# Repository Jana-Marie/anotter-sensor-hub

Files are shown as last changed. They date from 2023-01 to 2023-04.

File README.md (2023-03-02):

# anotter-sensor-hub

This is an ESP32-based environmental sensor hub that comes with a Prometheus interface. It is designed to work perfectly with Sensirion SEN05x sensors, such as the depictured SEN055. These sensors provide PM1, PM2.5, PM4, PM10, temperature, humidity, VOC, and NOC indices. In addition, other I2C, SPI, or PWM sensors can be added to the designated connectors. All ESP32 pins are broken out, allowing you to connect any sensor imaginable to the host board.

The PCB and components (w/o SEN055) are about ~5$, with SEN055 it comes up to ~40€/sensor node. 

<table>
  <tbody>
    <tr>
      <td>
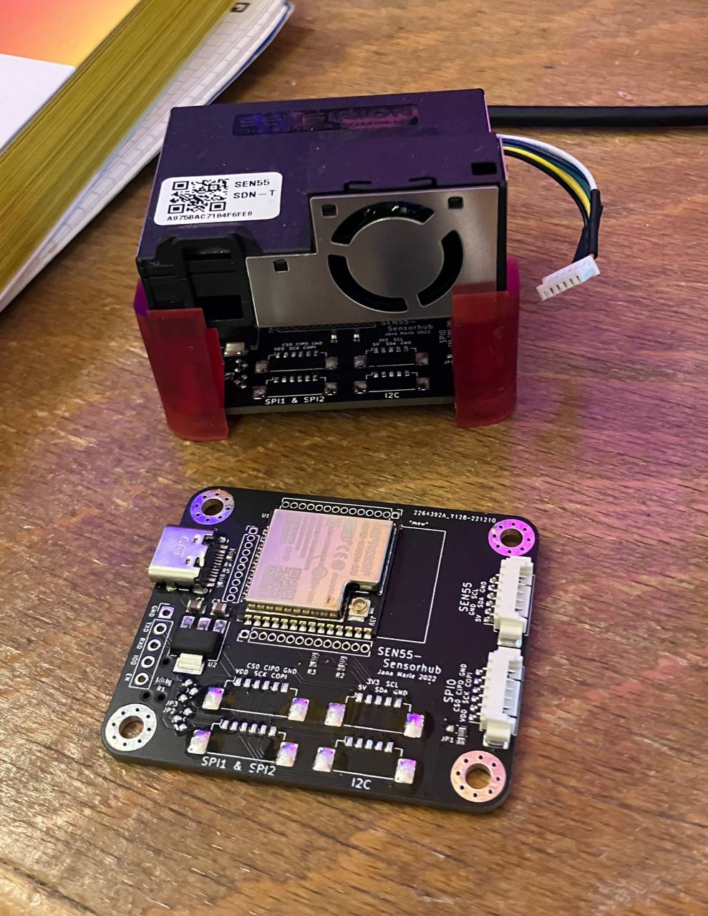
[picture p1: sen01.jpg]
        
      </td>
      <td>
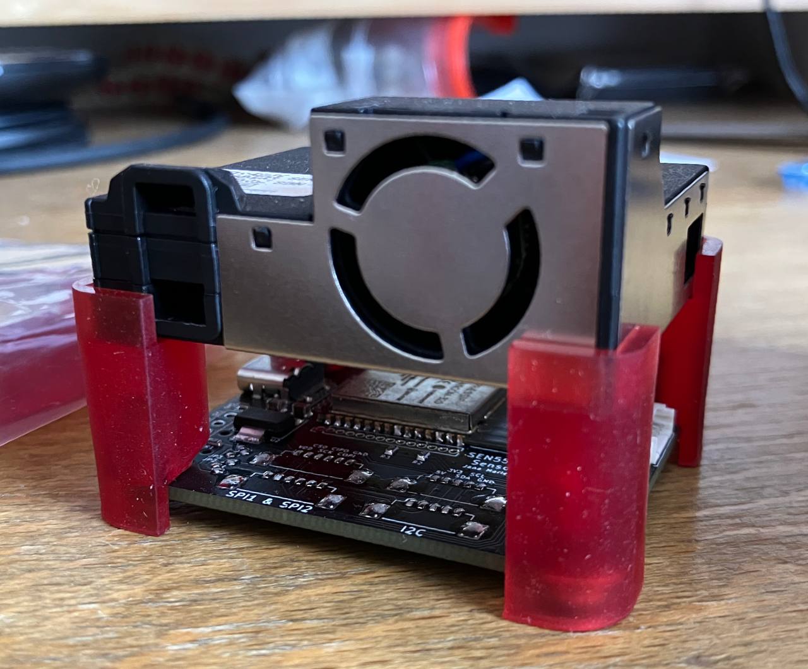
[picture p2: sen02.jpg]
        
      </td>
    </tr>
    <tr>
      <td colspan="2">
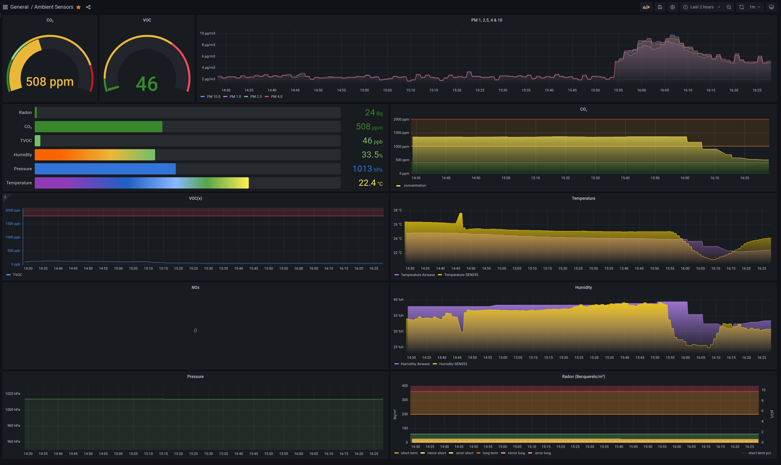
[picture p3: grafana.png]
        
      </td>
    </tr>
  </tbody>
</table>

## Notes

 - Cable: [JST GHR 6Pin to Molex PicoBlade 6Pin](https://www.ebay.de/itm/183753208063)
 - Sensor: [SEN055](https://www.mouser.de/ProductDetail/Sensirion/SEN55-SDN-T)
 - 3D-Print: [4x foot](https://github.com/Jana-Marie/anotter-sensor-hub/blob/main/mechanical/anotter-sensor-hub-foot.stl)

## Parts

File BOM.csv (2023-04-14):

Part | Footprint | Designator | Quantity
1uF | 0805 | C1,C2,C3 | 3
PicoBlade 6P | PicoBlade 6P | J2 | 1
USB Type-C 16P | USB Type-C 16P | J5 | 1
5k1 | 0603 | R1,R2,R3,R4,R5 | 5
ESP32-WROOM-32 | ESP32-WROOM-32 | U1 | 1
AMS1117-3.3 | SOT-223-3 | U2 | 1

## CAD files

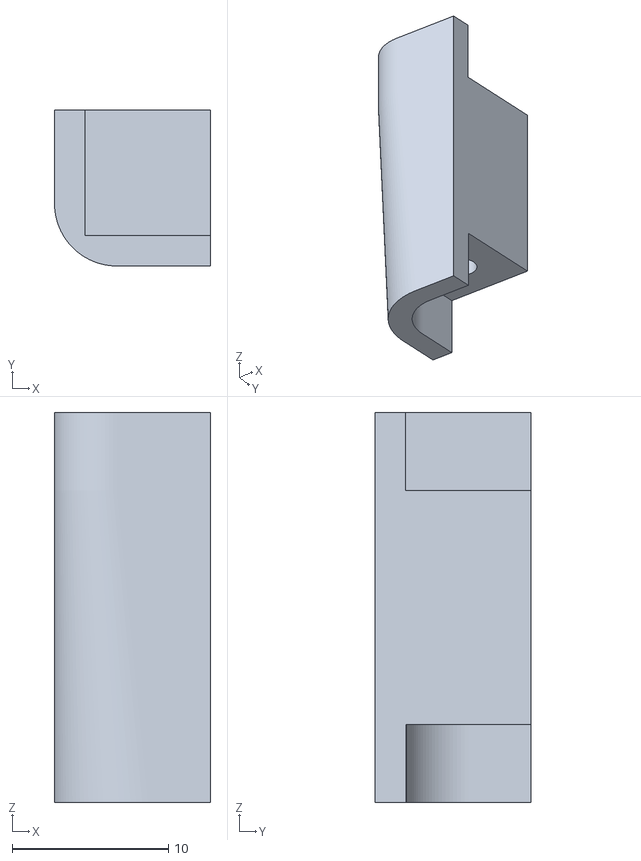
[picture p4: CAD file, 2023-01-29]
mechanical/anotter-sensor-hub-foot.stl
10.0 x 10.0 x 25.0

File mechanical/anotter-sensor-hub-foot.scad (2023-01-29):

$fn = 100;

if($preview){
    pcb();
    translate([1*44.3/2,1*35.3/2,1.6])rotate([0,0,180])stand();
    translate([1*44.3/2,-1*35.3/2,1.6])rotate([0,0,90])stand();
    translate([-1*44.3/2,1*35.3/2,1.6])rotate([0,0,270])stand();
    translate([-1*44.3/2,-1*35.3/2,1.6])rotate([0,0,0])stand();
    translate([0,0,1.6+15])sensor();
} else {
    stand();
}

module stand(h=15,h2=5){
    color("pink")
    difference(){
        union(){
            // outer hull
            hull(){
                // inner structure
                union(){
                    translate([0,2,h/2])cube([8,4,h],center=true);
                    translate([2,0,h/2])cube([4,8,h],center=true);
                    cylinder(r=4,h=h);
                }
                // lower hull
                union(){
                    translate([0,2,-h2/2])cube([12,4,h2],center=true);
                    translate([2,0,-h2/2])cube([4,12,h2],center=true);
                    translate([0,0,-h2])cylinder(r=6,h=h2);
                }
                // upper hull
                union(){
                    translate([0,1,h+h2/2])cube([12,6,h2],center=true);
                    translate([1,0,h+h2/2])cube([6,12,h2],center=true);
                    translate([-2,-2,h])cylinder(r=4,h=h2);
                }
            }
        } union(){
            // screwholes
            translate([0,0,-0.01])cylinder(d=2.8,h=h/3*2);
            // upper cutout
            translate([0,0,h+h/4])cube([8.1,8.1,h/2],center=true);
            // PCB cutout
            union(){
                translate([0,2,-h/2])cube([8,4,h],center=true);
                translate([2,0,-h/2])cube([4,8,h],center=true);
                translate([0,6,0])cube([12,4,h*3],center=true);
                translate([6,0,0])cube([4,12,h*3],center=true);
                translate([0,0,-h])cylinder(r=4,h=h);
            }
        }
    }
}

module pcb(thickness=1.6){
    difference(){
        union(){
            // PCB
            color("green")
            minkowski(){
                r=4;
                translate([0,0,thickness/2-0.1/2])cube([52.3-r-r,43.4-r-r, thickness-0.1],center=true);
                cylinder(r=r,h=0.1);
            }
            // Screwholeplates
            color("gold")
            for(i = [-1:2:1]){
                for(j = [-1:2:1]){
                    translate([i*44.3/2,j*35.3/2,0])cylinder(d=6.4,h=thickness+0.01);
                }
            }
            // ESP32
            translate([-1,10,thickness])
            union(){
                color("black")translate([0,0,0.6/2])cube([25,18,0.6],center=true);
                color("silver")translate([-2.75,0,0.6+1.2/2])cube([18,16.5,1.2],center=true);
            }
            // USB
            color("silver")translate([-22,8,3.2/2+thickness])cube([9,7.4,3.2],center=true);
        } union(){
            // Screwholes
            for(i = [-1:2:1]){
                for(j = [-1:2:1]){
                    translate([i*44.3/2,j*35.3/2,-thickness/2])cylinder(d=3.2,h=thickness*2);
                }
            }
        }
    }
}

module sensor(){
    difference(){
        union(){
            // main body
            color("DarkSlateGray")translate([0,0,13.2/2])cube([52.3,43.3,13.2],center=true);
            // fan
            color("DarkSlateGray")translate([52.2/2-27.24/2,-43.2/2+15/2,22.3/2])cube([27.24,15,22.3],center=true);
            // intake
            color("DarkSlateGray")translate([-52.2/2+27.24/2,-43.2/2+10/2,16.7/2])cube([13.69,10,16.7],center=true);
        } union(){
        }
    }
}

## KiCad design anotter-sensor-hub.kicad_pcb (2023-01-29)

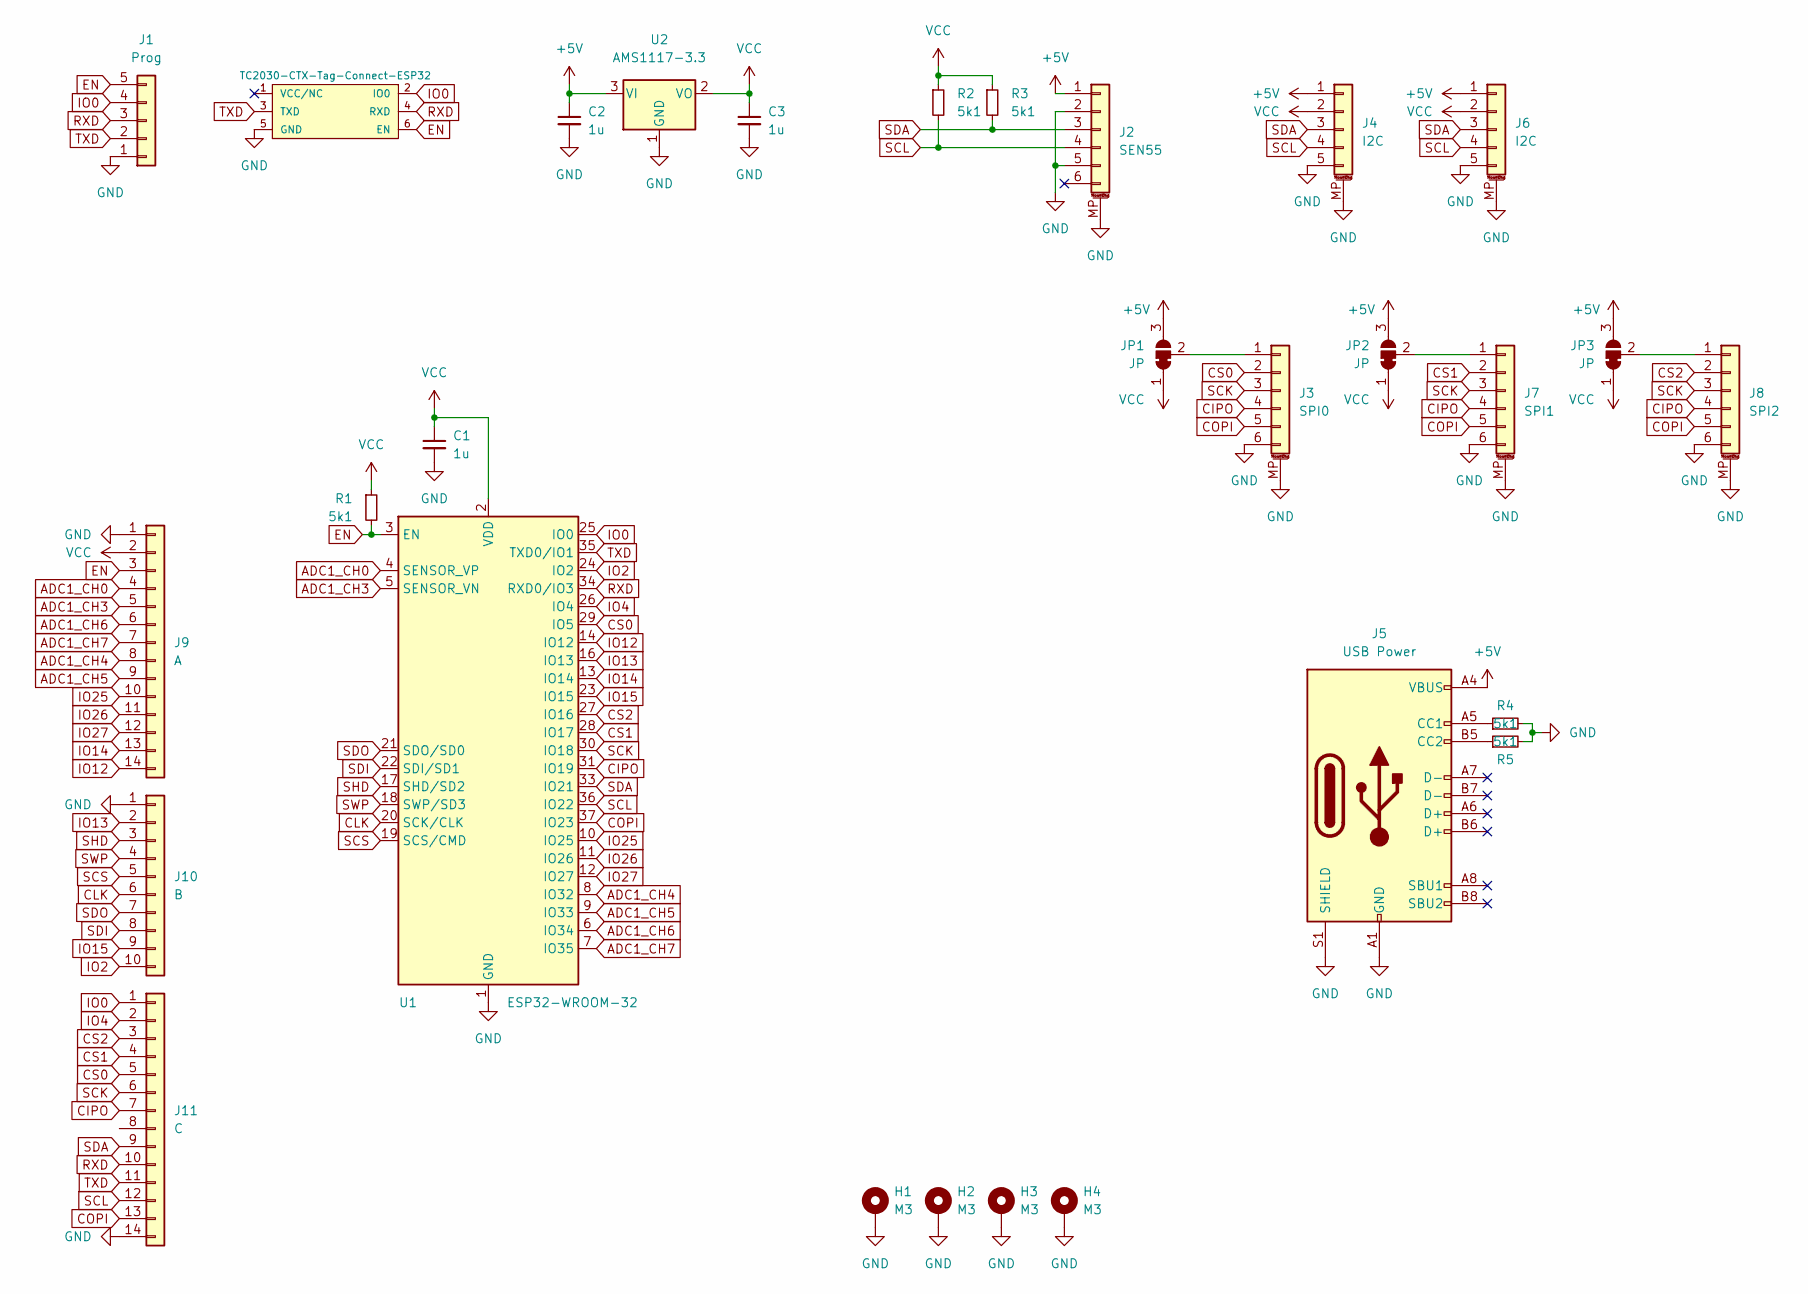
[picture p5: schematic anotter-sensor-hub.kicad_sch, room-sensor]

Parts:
C1, C2, C3: 1u; C_0805
H1, H2, H3, H4: M3; MountingHole_3.2mm_M3_Pad_Via
J1: Prog; PinHeader_1x05_P2.54mm_Vertical
J2: SEN55; Molex_PicoBlade_53261-0671_1x06-1MP_P1.25mm_Horizontal
J3: SPI0; Molex_PicoBlade_53261-0671_1x06-1MP_P1.25mm_Horizontal
J4, J6: I2C; Molex_PicoBlade_53398-0571_1x05-1MP_P1.25mm_Vertical
J5: USB Power; USB-C 16Pin
J7: SPI1; Molex_PicoBlade_53398-0671_1x06-1MP_P1.25mm_Vertical
J8: SPI2; Molex_PicoBlade_53398-0671_1x06-1MP_P1.25mm_Vertical
J9: A; PinHeader_1x14_P1.27mm_Vertical
J10: B; PinHeader_1x10_P1.27mm_Vertical
J11: C; PinHeader_1x14_P1.27mm_Vertical
JP1, JP2, JP3: JP; J_0603_90
P1: TC2030-CTX-Tag-Connect-ESP32; TC2030
R1, R2, R3, R4, R5: 5k1; R_0603
U1: ESP32-WROOM-32
U2: AMS1117-3.3; SOT-223-3_TabPin2

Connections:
+5V: C2.1, J2.1, J4.1, J5.A4 (VBUS), J5.A9 (VBUS), J5.B4 (VBUS), J5.B9 (VBUS), J6.1, JP1.3 (B), JP2.3 (B), JP3.3 (B), U2.3 (VI)
ADC1_CH0: J9.4, U1.4 (SENSOR_VP)
ADC1_CH3: J9.5, U1.5 (SENSOR_VN)
ADC1_CH4: J9.8, U1.8 (IO32)
ADC1_CH5: J9.9, U1.9 (IO33)
ADC1_CH6: J9.6, U1.6 (IO34)
ADC1_CH7: J9.7, U1.7 (IO35)
CIPO: J3.4, J7.4, J8.4, J11.7, U1.31 (IO19)
CLK: J10.6, U1.20 (SCK/CLK)
COPI: J3.5, J7.5, J8.5, J11.13, U1.37 (IO23)
CS0: J3.2, J11.5, U1.29 (IO5)
CS1: J7.2, J11.4, U1.28 (IO17)
CS2: J8.2, J11.3, U1.27 (IO16)
EN: J1.5, J9.3, P1.6 (EN), R1.2, U1.3 (EN)
GND: C1.2, C2.2, C3.2, H1.1, H2.1, H3.1, H4.1, J1.1, J2.2, J2.5, J2.MP (MountPin), J3.6, J3.MP (MountPin), J4.5, J4.MP (MountPin), J5.A1 (GND), J5.A12 (GND), J5.B1 (GND), J5.B12 (GND), J5.S1 (SHIELD), J6.5, J6.MP (MountPin), J7.6, J7.MP (MountPin), J8.6, J8.MP (MountPin), J9.1, J10.1, J11.14, P1.5 (GND), R4.2, R5.2, U1.1 (GND), U1.15 (GND), U1.38 (GND), U1.39 (GND), U2.1 (GND)
IO0: J1.4, J11.1, P1.2 (IO0), U1.25 (IO0)
IO2: J10.10, U1.24 (IO2)
IO4: J11.2, U1.26 (IO4)
IO12: J9.14, U1.14 (IO12)
IO13: J10.2, U1.16 (IO13)
IO14: J9.13, U1.13 (IO14)
IO15: J10.9, U1.23 (IO15)
IO25: J9.10, U1.10 (IO25)
IO26: J9.11, U1.11 (IO26)
IO27: J9.12, U1.12 (IO27)
unnamed: J5.A5 (CC1), R4.1
unnamed: J5.B5 (CC2), R5.1
unnamed: J3.1, JP1.2 (C)
unnamed: J7.1, JP2.2 (C)
unnamed: J8.1, JP3.2 (C)
RXD: J1.3, J11.10, P1.4 (RXD), U1.34 (RXD0/IO3)
SCK: J3.3, J7.3, J8.3, J11.6, U1.30 (IO18)
SCL: J2.4, J4.4, J6.4, J11.12, R2.2, U1.36 (IO22)
SCS: J10.5, U1.19 (SCS/CMD)
SDA: J2.3, J4.3, J6.3, J11.9, R3.2, U1.33 (IO21)
SDI: J10.8, U1.22 (SDI/SD1)
SDO: J10.7, U1.21 (SDO/SD0)
SHD: J10.3, U1.17 (SHD/SD2)
SWP: J10.4, U1.18 (SWP/SD3)
TXD: J1.2, J11.11, P1.3 (TXD), U1.35 (TXD0/IO1)
VCC: C1.1, C3.1, J4.2, J6.2, J9.2, JP1.1 (A), JP2.1 (A), JP3.1 (A), R1.1, R2.1, R3.1, U1.2 (VDD), U2.2 (VO)

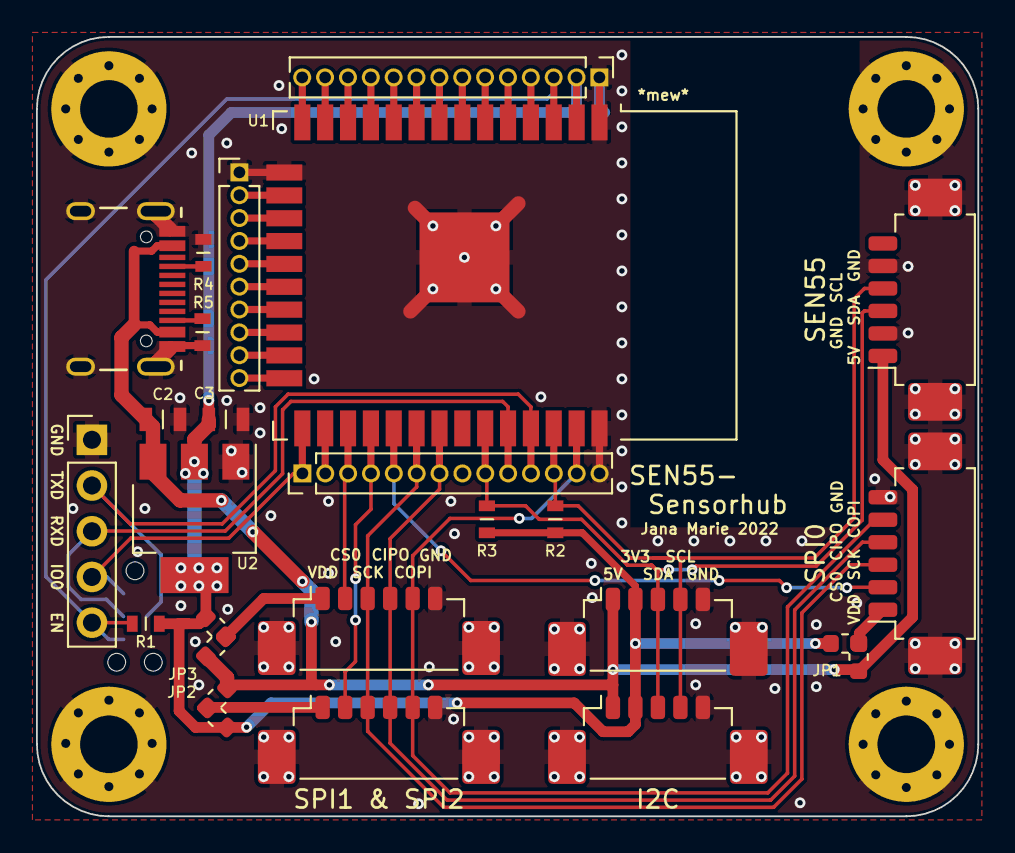
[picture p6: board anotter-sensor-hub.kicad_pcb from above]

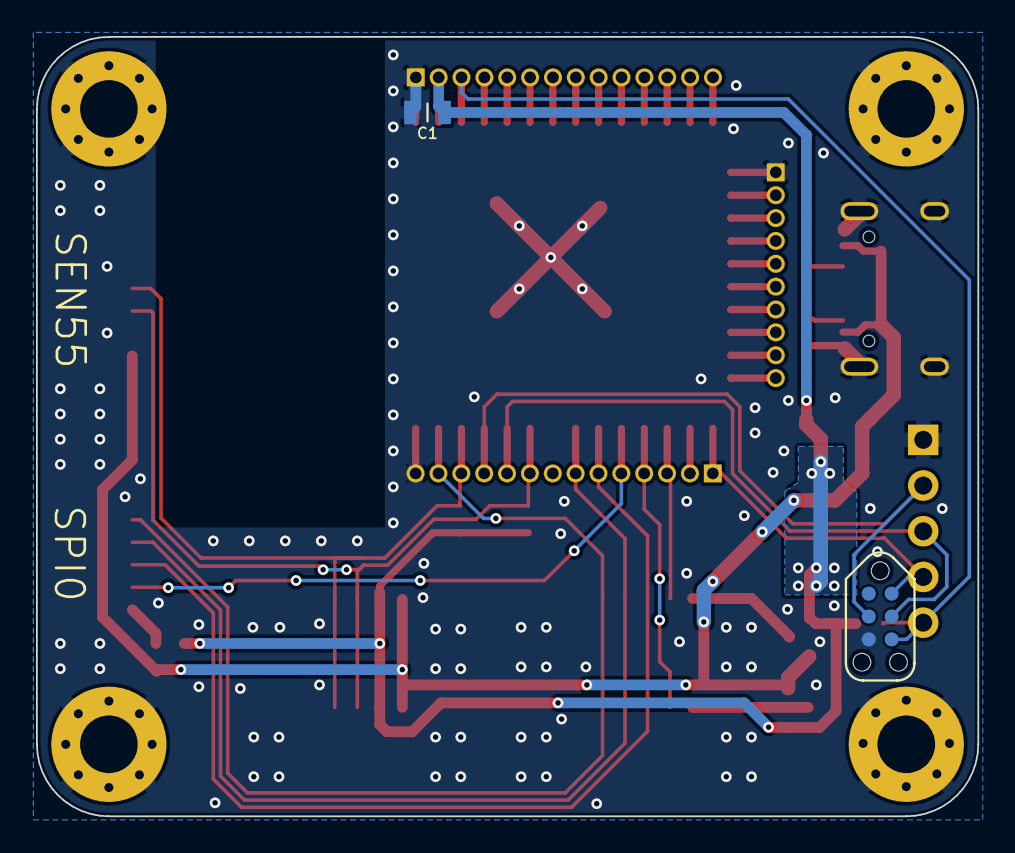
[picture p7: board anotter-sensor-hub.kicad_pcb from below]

Board: 2 copper layers, 52.3 x 43.3 mm, 29 parts (2 on the bottom side), 41 nets.

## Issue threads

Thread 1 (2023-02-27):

Is something missing

versamodule, 2023-02-27:
Is there a file missing?  How is the grafana web page connecting to the ESP32 ?

Jana-Marie, 2023-02-27:
Via Prometheus, there is no file missing :)

versamodule, 2023-02-28:
Thanks for the reply.

Closed 2023-02-28.

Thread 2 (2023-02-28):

Add license information

vazhnov, 2023-02-28:
Hello!

I found this project from https://hackaday.com/2023/02/27/hacker-friendly-and-elegant-air-quality-sensor-hub/

Could you please add information about the license of this repository — is it allowed to copy, change and use the code and PCB files in any purpose?
 It would be great to see any popular open source license.

Jana-Marie, 2023-02-28:
ooh, yes, thank you! I will add that

Jana-Marie, 2023-02-28:
Done, it is allowed to copy, change and use the code in any purpose (if I did the licensing correctly ^^). Best, Jana

vazhnov, 2023-02-28:
CERN-OHL-S-2.0 license — great!
@Jana-Marie, thank you very much!

Closed 2023-02-28.

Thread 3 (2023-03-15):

More info about components

Dredok, 2023-03-15:
Hi Jana,
thanks for the project, I'd like to make it but my knowledge of electronics is VERY basic. So I see the ESP32, a voltage regulator? and a couple of connectors. The connector is a JST GHR 6P if i'm not mistaken; and a usb-c which I assume is for power and programming the ESP32.

A basic BOM with these components would definitely help n00bs like me!

Jana-Marie, 2023-03-17:
Oh, yes. I will add that in a bit!

jens112131, 2023-04-14:
I would also like to build it. Already got the PCB but a BOM would be very helpful.

Jana-Marie, 2023-04-14:
Sorry for the delay, here is the BOM! https://github.com/Jana-Marie/anotter-sensor-hub/blob/main/BOM.csv

Closed 2023-04-14.

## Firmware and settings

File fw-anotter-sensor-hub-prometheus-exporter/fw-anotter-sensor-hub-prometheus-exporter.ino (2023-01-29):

#include <Arduino.h>
#include <SensirionI2CSen5x.h>
#include <Wire.h>
#include <WiFi.h>

SensirionI2CSen5x sen5x;

const char* ssid = "ssid";
const char* password = "pw";

WiFiServer server(80);

unsigned long currentTime = millis();
unsigned long previousTime = 0;
const long timeoutTime = 2000;

void setup() {
  Wire.begin();
  Serial.begin(115200);
  sen5x.begin(Wire);
  uint16_t error = sen5x.deviceReset();

  float tempOffset = 0.0;
  error = sen5x.setTemperatureOffsetSimple(tempOffset);
  error = sen5x.startMeasurement();

  WiFi.begin(ssid, password);
  while (WiFi.status() != WL_CONNECTED) {
    delay(500);
    Serial.print(".");
  }

  Serial.println("");
  Serial.println("WiFi connected.");
  Serial.println("IP address: ");
  Serial.println(WiFi.localIP());
  server.begin();
}

void loop() {
  WiFiClient client = server.available();

  if (client) {
    float massConcentrationPm1p0;
    float massConcentrationPm2p5;
    float massConcentrationPm4p0;
    float massConcentrationPm10p0;
    float ambientHumidity;
    float ambientTemperature;
    float vocIndex;
    float noxIndex;
    currentTime = millis();
    previousTime = currentTime;
    String line = "";
    while (client.connected() && currentTime - previousTime <= timeoutTime) {
      currentTime = millis();
      if (client.available()) {
        char c = client.read();
        if (c == '\n') {
          if (line.length() == 0) {

            uint16_t error = sen5x.readMeasuredValues(
                               massConcentrationPm1p0, massConcentrationPm2p5, massConcentrationPm4p0,
                               massConcentrationPm10p0, ambientHumidity, ambientTemperature, vocIndex,
                               noxIndex);

            client.println("HTTP/1.1 200 OK");
            client.println("Content-type:text/plain");
            client.println("Connection: close");
            client.println();

            client.print("sen055_mass_concentration{size=\"pm_1_0\"} ");  client.print(massConcentrationPm1p0); client.print('\n');
            client.print("sen055_mass_concentration{size=\"pm_2_5\"} ");  client.print(massConcentrationPm2p5); client.print('\n');
            client.print("sen055_mass_concentration{size=\"pm_4_0\"} ");  client.print(massConcentrationPm4p0); client.print('\n');
            client.print("sen055_mass_concentration{size=\"pm_10_0\"} "); client.print(massConcentrationPm10p0); client.print('\n');
            client.print("sen055_ambient_humidity{} ");     client.print(ambientHumidity); client.print('\n');
            client.print("sen055_ambient_temperature{} ");  client.print(ambientTemperature); client.print('\n');
            client.print("sen055_voc_index{} ");            client.print(vocIndex); client.print('\n');
            client.print("sen055_nox_index{} ");            client.print(noxIndex); client.print('\n');

          } else {
            line = "";
          }
        } else if (c != '\r') {
          line += c;
        }
      }
    }
    client.stop();
    
    Serial.print("MassConcentrationPm1p0:");
    Serial.print(massConcentrationPm1p0);
    Serial.print("\t");
    Serial.print("MassConcentrationPm2p5:");
    Serial.print(massConcentrationPm2p5);
    Serial.print("\t");
    Serial.print("MassConcentrationPm4p0:");
    Serial.print(massConcentrationPm4p0);
    Serial.print("\t");
    Serial.print("MassConcentrationPm10p0:");
    Serial.print(massConcentrationPm10p0);
    Serial.print("\t");
    Serial.print("AmbientHumidity:");
    if (isnan(ambientHumidity)) {
      Serial.print("n/a");
    } else {
      Serial.print(ambientHumidity);
    }
    Serial.print("\t");
    Serial.print("AmbientTemperature:");
    if (isnan(ambientTemperature)) {
      Serial.print("n/a");
    } else {
      Serial.print(ambientTemperature);
    }
    Serial.print("\t");
    Serial.print("VocIndex:");
    if (isnan(vocIndex)) {
      Serial.print("n/a");
    } else {
      Serial.print(vocIndex);
    }
    Serial.print("\t");
    Serial.print("NoxIndex:");
    if (isnan(noxIndex)) {
      Serial.println("n/a");
    } else {
      Serial.println(noxIndex);
    }
  }
}

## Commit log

2023-01-29 initial hardware commit
    [anotter-sensor-hub.kicad_pcb, anotter-sensor-hub.kicad_sch]
2023-01-29 added 3D files
    [anotter-sensor-hub-foot.scad, anotter-sensor-hub-foot.stl]
2023-04-14 updated BOM
    [BOM.csv]
